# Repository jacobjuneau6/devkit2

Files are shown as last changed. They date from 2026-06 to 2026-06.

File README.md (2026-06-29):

# devkit2

A compact ESP32-S3 development board designed for rapid prototyping and embedded projects.

## Features

- **ESP32-S3-WROOM-1** module — dual-core Xtensa LX7, 2.4 GHz Wi-Fi, BLE 5.0, 8 MB PSRAM, 16 MB Flash
- **USB-C** connector for power, programming, and serial monitor
- **WS2812B** addressable RGB LED on GPIO 2
- **microSD card** slot (TF-PUSH) connected via SPI
- **2× tactile push buttons** — Boot (GPIO 0) and Reset (EN)
- **2× 20-pin breakout headers** bringing out all available GPIO, power rails, and peripheral signals
- **3.3 V LDO regulator** (TPS74533) — up to 500 mA output, 6.5 V max input
- **Compact form factor** — fits on a breadboard with one row of pins free on each side

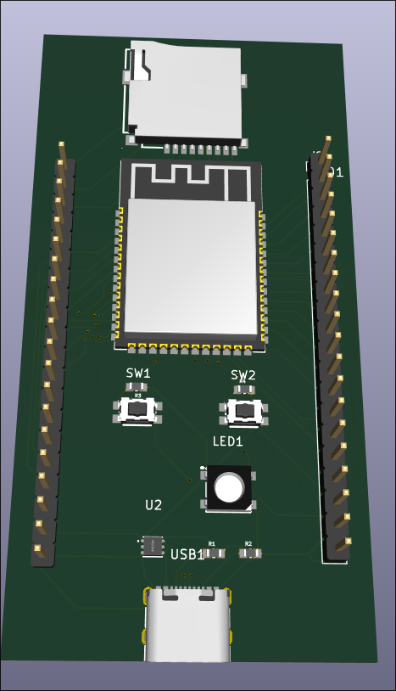
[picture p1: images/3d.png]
devkit2 3D render


## Pin Map

```
                    ┌──────────────────┐
             3.3V —│ J1               │— GND
             EN   —│                  │— VIN (5 V)
            IO4   —│                  │— IO5
            IO6   —│                  │— IO7
            IO15  —│                  │— IO8
            IO16  —│                  │— IO9
            IO17  —│                  │— IO10
            IO18  —│                  │— IO11
            IO19  —│                  │— IO12
            IO20  —│                  │— IO13
            IO21  —│    ESP32-S3      │— IO14
            IO26  —│    devkit2       │— IO38
            IO35  —│                  │— IO39
            IO36  —│                  │— IO40
            IO37  —│                  │— IO41
            IO42  —│                  │— IO45
            IO43  —│                  │— IO46
            IO44  —│                  │— IO47
            GND   —│                  │— IO2  (onboard LED)
            5 V   —│                  │— IO0  (Boot button)
                   └──────────────────┘
```

| Peripheral | GPIO | Notes |
|---|---|---|
| WS2812B LED | 2 | DIN, use NeoPixel lib |
| Boot button | 0 | Pull LOW to enter download mode |
| Reset button| EN | Pulls EN pin LOW |
| microSD CS  | 5 | SPI chip select |
| microSD MOSI| 11 | SPI data |
| microSD MISO| 13 | SPI data |
| microSD SCK | 12 | SPI clock |

## Getting Started

### 1. Add Board Support

Install the **esp32** board package by Espressif in the Arduino IDE:

1. Open **File → Preferences**
2. Add this URL to **Additional Boards Manager URLs**:
   ```
   https://espressif.github.io/arduino-esp32/package_esp32_index.json
   ```
3. Open **Tools → Board → Boards Manager**, search for `esp32`, and install **esp32 by Espressif Systems**

### 2. Select Board Settings

| Setting | Value |
|---|---|
| Board | ESP32S3 Dev Module |
| USB CDC On Boot  | Enabled |
| Flash Size | 16 MB (128 Mb) |
| PSRAM | OPI PSRAM |
| Upload Mode | UART / Hardware CDC |

### 3. Install Libraries

Install these libraries via **Tools → Manage Libraries**:

- **Adafruit NeoPixel** — for the onboard WS2812B LED
- **SD** (built-in, or **SdFat**) — for the microSD slot

### 4. Upload the Demo

Hold **Boot** (SW1), press and release **Reset** (SW2), then release **Boot** to enter download mode. Open `CODE/demo/demo.ino` in the Arduino IDE, select the correct port, and hit **Upload**.

## Bill of Materials

| Designator | Qty | Value | Footprint | LCSC # |
|---|-----|---|---|---|
| U1 | 1 | ESP32-S3-WROOM-1 | WIRELM-SMD ESP32-S3-WROOM-1 | C2913201  |
| U2 | 1 | TPS74533PCQWDRVRQ1  | WSON-6 2.0×2.0 mm | C2860924  |
| USB1 | 1 | TYPE-C 16PIN 2MD | USB-C SMD 16-pin | C2765186  |
| LED1 | 1 | WS2812B-B/W | LED-SMD 5.0×5.0 mm | C2761795  |
| CARD1 | 1 | TF PUSH | TF-SMD push-push | C393941 |
| J1, J2 | 2 | PINHD 1×20 Male | PinHeader 1×20 2.54 mm | — |
| SW1, SW2  | 2 | KMR221NGLFS | KEY-SMD 4.2×2.8 mm | C269272 |
| R1, R2 | 2 | RT0603BRE075K1L | 0603 (1608 Metric) | C728607 |
| R3, R4 | 2 | RT0603BRE0710KL | 0603 (1608 Metric) | C6277183  |

- **R1, R2** = 5.1 kΩ thin-film — USB-C CC pull-downs
- **R3, R4** = 10 kΩ thick-film — EN and BOOT pull-ups
- **SW1** = Reset, **SW2** = Boot
- All passives are 0603 imperial (1608 metric)

## Hardware

Board files live in [`BOARD/`](BOARD/). The project was designed in **KiCad 8**.

**🔗 [View schematic & PCB interactively on KiCanvas](https://kicanvas.org/?github=https://github.com/jacobjuneau6/devkit2/blob/main/BOARD/Board/Board.kicad_pro)**

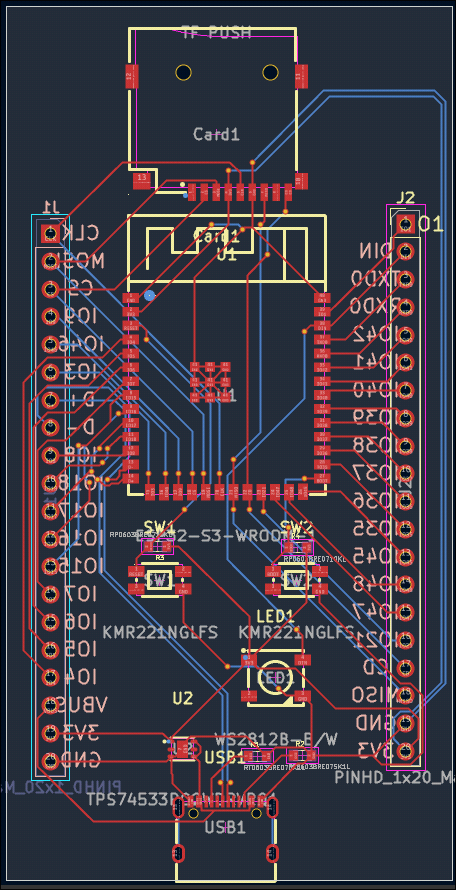
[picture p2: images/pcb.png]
PCB layout


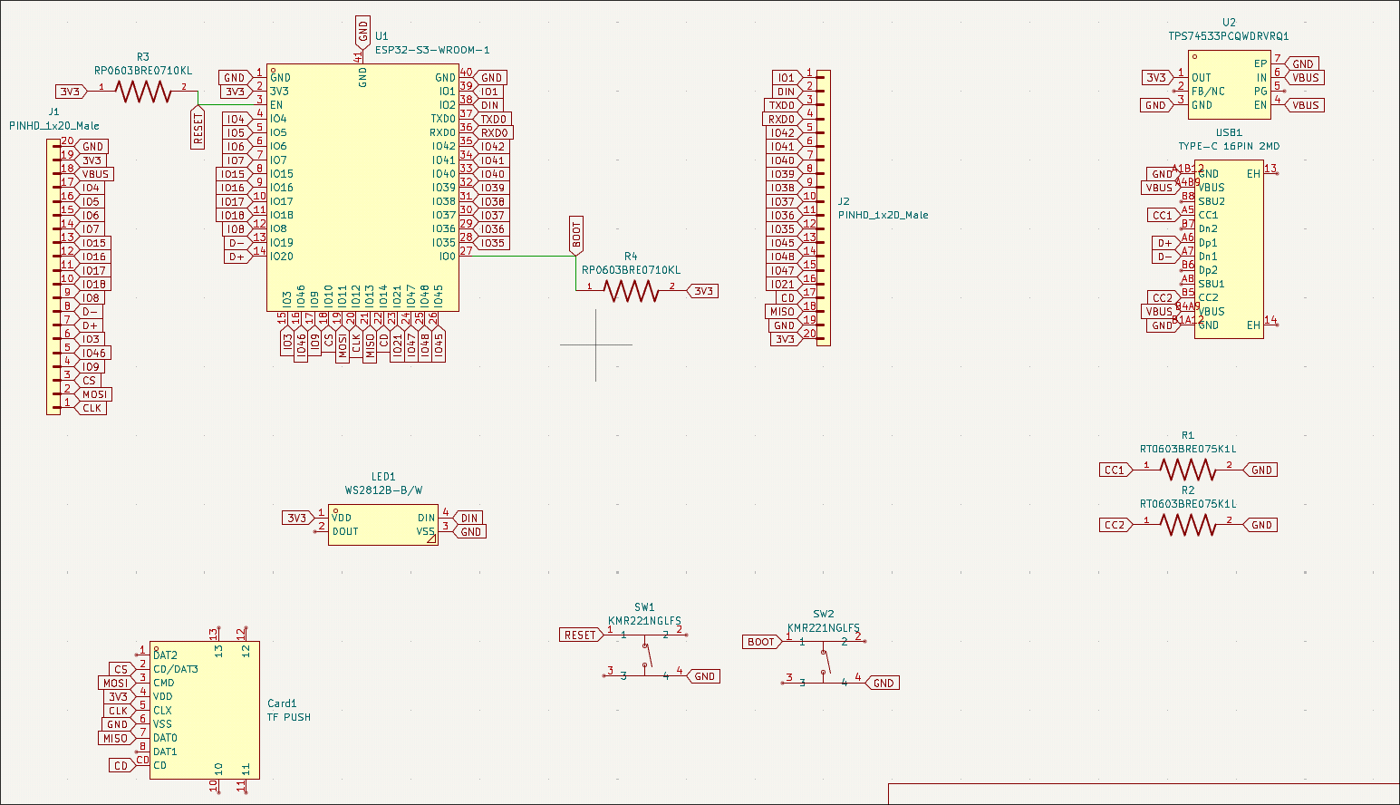
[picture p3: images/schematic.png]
Schematic


| Directory | Contents |
|---|---|
| `BOARD/Board/` | Schematic, PCB, project files |
| `BOARD/Board/gbrs/` | Gerber files (JLCPCB ready)  |
| `BOARD/Board/production/` | BOM, CPL, netlist |
| `BOARD/CAD/` | 3D STEP model |

## License

Hardware and software are released under the [MIT License](LICENSE).

---

Built by [jacobjuneau6](https://github.com/jacobjuneau6)

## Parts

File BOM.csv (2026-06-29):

Designator | Footprint | Quantity | Value | LCSC Part #
CARD1 | TF-SMD_TF-PUSH | 1 | TF PUSH | C393941
J1, J2 | PinHeader_1x20_P2.54mm_Vertical | 2 | PINHD_1x20_Male
LED1 | LED-SMD_4P-L5.0-W5.0-TL_WS2812B-B | 1 | WS2812B-B/W | C2761795
R1, R2 | RESC1608X55N | 2 | RT0603BRE075K1L | C728607
R3, R4 | RESC1608X55N | 2 | RP0603BRE0710KL | C6277183
SW1, SW2 | KEY-SMD_4P-L4.2-W2.8-P1.60-LS4.6 | 2 | KMR221NGLFS | C269272
U1 | WIRELM-SMD_ESP32-S3-WROOM-1 | 1 | ESP32-S3-WROOM-1 | C2913201
U2 | WSON-6_L2.0-W2.0-P0.65-TL-EP | 1 | TPS74533PCQWDRVRQ1 | C2860924
USB1 | USB-C-SMD_TYPE-C-16PIN-2MD-073 | 1 | TYPE-C 16PIN 2MD | C2765186

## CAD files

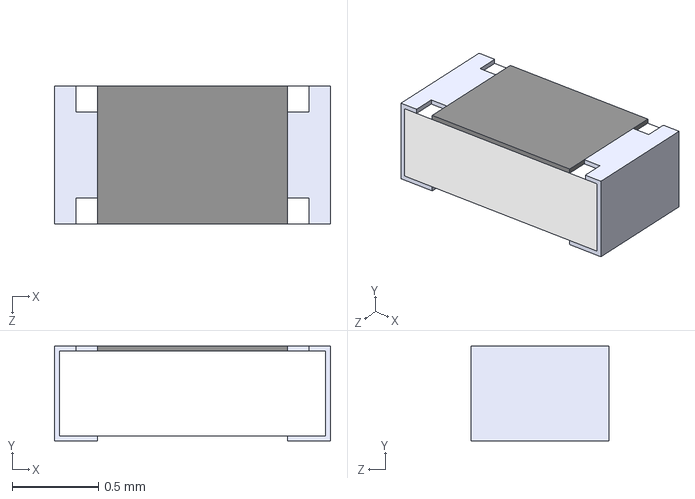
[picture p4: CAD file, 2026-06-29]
BOARD/Board/staging/RT0603BRE075K1L/RT0603BRE075K1L.step
1.60 x 0.55 x 0.8 mm

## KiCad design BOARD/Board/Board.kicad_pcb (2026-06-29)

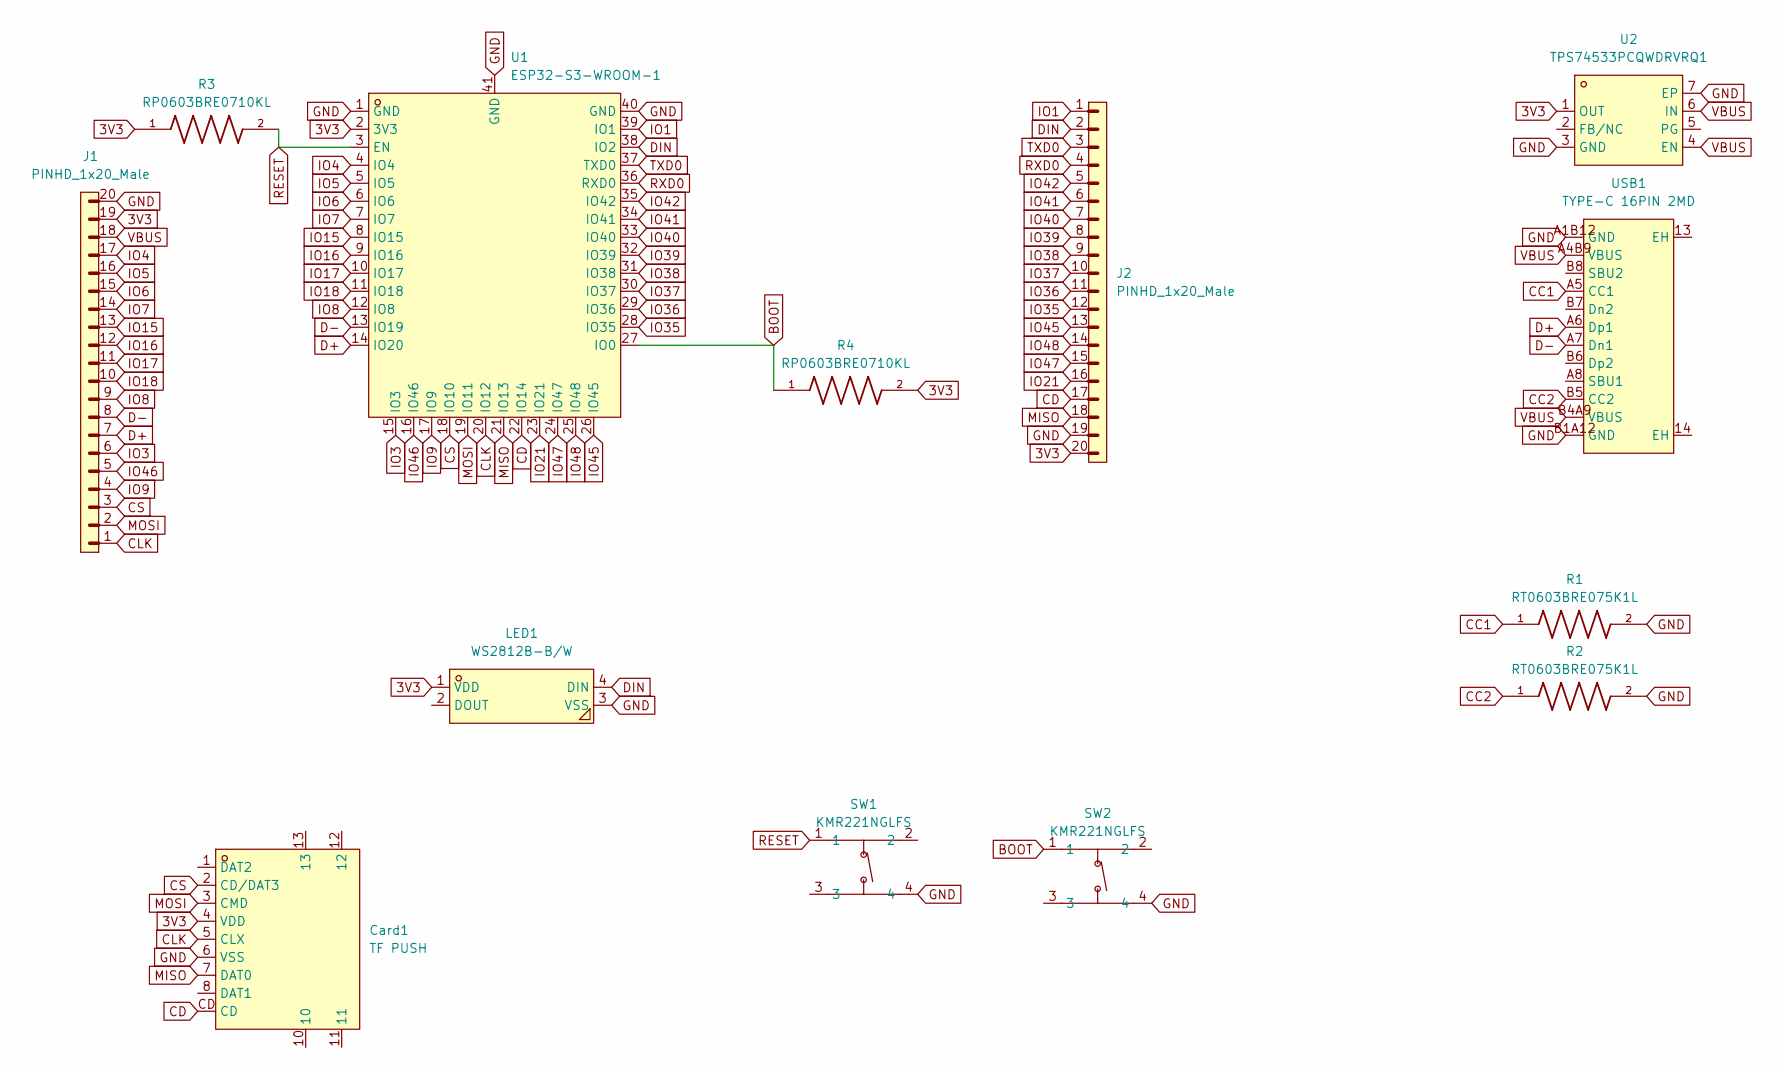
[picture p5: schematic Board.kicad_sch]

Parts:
Card1: TF PUSH; TF-SMD_TF-PUSH; MPN TF PUSH; LCSC Part C393941
J1, J2: PINHD_1x20_Male; PinHeader_1x20_P2.54mm_Vertical
LED1: WS2812B-B/W; LED-SMD_4P-L5.0-W5.0-TL_WS2812B-B; MPN WS2812B-B/T; LCSC Part C2761795
R1, R2: RT0603BRE075K1L; RESC1608X55N; MPN TYPE-C 16PIN 2MD(073); LCSC Part C728607
R3, R4: RP0603BRE0710KL; RESC1608X55N; MPN TYPE-C 16PIN 2MD(073); LCSC Part C6277183
SW1, SW2: KMR221NGLFS; KEY-SMD_4P-L4.2-W2.8-P1.60-LS4.6; MPN KMR221NGLFS; LCSC Part C269272
U1: ESP32-S3-WROOM-1; WIRELM-SMD_ESP32-S3-WROOM-1; MPN ESP32-S3-WROOM-1-N8R8; LCSC Part C2913201
U2: TPS74533PCQWDRVRQ1; WSON-6_L2.0-W2.0-P0.65-TL-EP; MPN TPS74533PCQWDRVRQ1; LCSC Part C2860924
USB1: TYPE-C 16PIN 2MD; USB-C-SMD_TYPE-C-16PIN-2MD-073; MPN TYPE-C 16PIN 2MD(073); LCSC Part C2765186

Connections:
3V3: Card1.4 (VDD), J1.19, J2.20, LED1.1 (VDD), R3.1, R4.2, U1.2 (3V3), U2.1 (OUT)
BOOT: R4.1, SW2.1, U1.27 (IO0)
CC1: R1.1, USB1.A5 (CC1)
CC2: R2.1, USB1.B5 (CC2)
CD: Card1.CD, J2.17, U1.22 (IO14)
CLK: Card1.5 (CLX), J1.1, U1.20 (IO12)
CS: Card1.2 (CD/DAT3), J1.3, U1.18 (IO10)
D+: J1.7, U1.14 (IO20), USB1.A6 (Dp1)
D-: J1.8, U1.13 (IO19), USB1.A7 (Dn1)
DIN: J2.2, LED1.4 (DIN), U1.38 (IO2)
GND: Card1.6 (VSS), J1.20, J2.19, LED1.3 (VSS), R1.2, R2.2, SW1.4, SW2.4, U1.1 (GND), U1.40 (GND), U1.41 (GND), U2.3 (GND), U2.7 (EP), USB1.A1B12 (GND), USB1.B1A12 (GND)
IO1: J2.1, U1.39 (IO1)
IO3: J1.6, U1.15 (IO3)
IO4: J1.17, U1.4 (IO4)
IO5: J1.16, U1.5 (IO5)
IO6: J1.15, U1.6 (IO6)
IO7: J1.14, U1.7 (IO7)
IO8: J1.9, U1.12 (IO8)
IO9: J1.4, U1.17 (IO9)
IO15: J1.13, U1.8 (IO15)
IO16: J1.12, U1.9 (IO16)
IO17: J1.11, U1.10 (IO17)
IO18: J1.10, U1.11 (IO18)
IO21: J2.16, U1.23 (IO21)
IO35: J2.12, U1.28 (IO35)
IO36: J2.11, U1.29 (IO36)
IO37: J2.10, U1.30 (IO37)
IO38: J2.9, U1.31 (IO38)
IO39: J2.8, U1.32 (IO39)
IO40: J2.7, U1.33 (IO40)
IO41: J2.6, U1.34 (IO41)
IO42: J2.5, U1.35 (IO42)
IO45: J2.13, U1.26 (IO45)
IO46: J1.5, U1.16 (IO46)
IO47: J2.15, U1.24 (IO47)
IO48: J2.14, U1.25 (IO48)
MISO: Card1.7 (DAT0), J2.18, U1.21 (IO13)
MOSI: Card1.3 (CMD), J1.2, U1.19 (IO11)
RESET: R3.2, SW1.1, U1.3 (EN)
RXD0: J2.4, U1.36 (RXD0)
TXD0: J2.3, U1.37 (TXD0)
VBUS: J1.18, U2.4 (EN), U2.6 (IN), USB1.A4B9 (VBUS), USB1.B4A9 (VBUS)

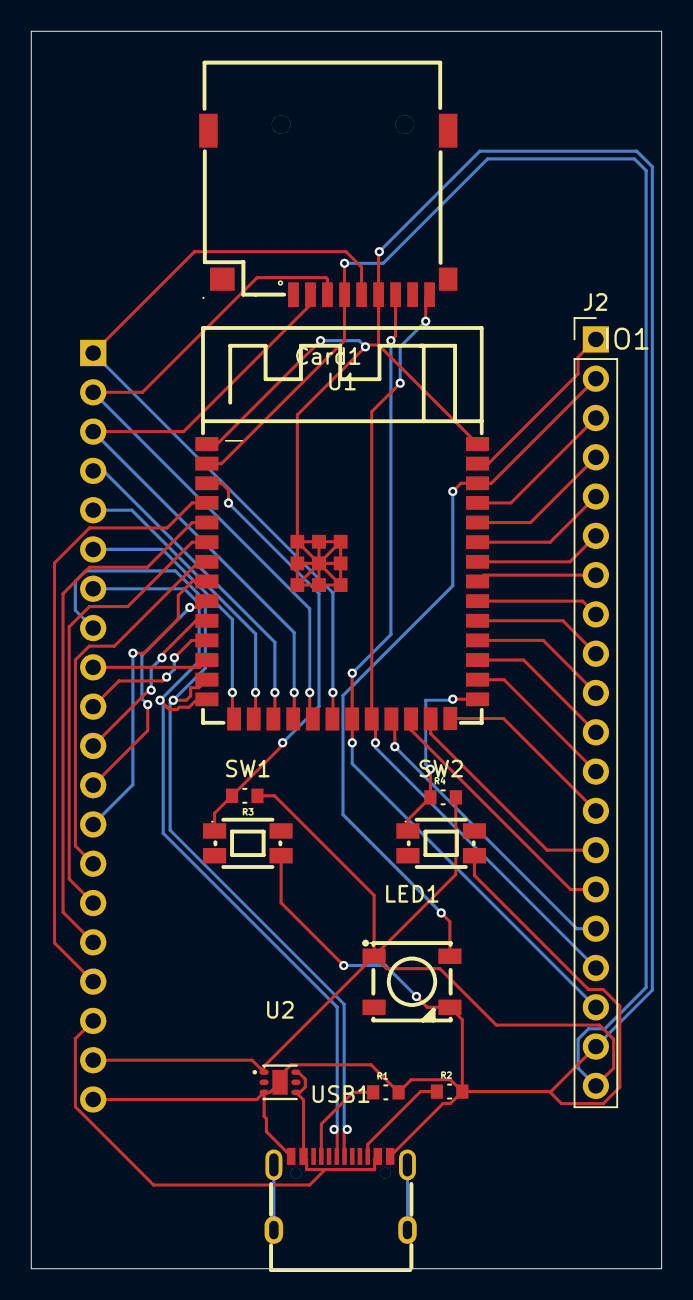
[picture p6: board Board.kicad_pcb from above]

Board: 2 copper layers, 40.8 x 80.0 mm, 13 parts (1 on the bottom side), 42 nets.

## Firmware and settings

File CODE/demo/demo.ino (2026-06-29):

/**
 * devkit2 Demo Sketch
 *
 * Demonstrates the onboard peripherals of the devkit2 ESP32-S3 board:
 *   - WS2812B RGB LED (GPIO 48) — color cycle + blink patterns
 *   - Boot button (GPIO 0) — cycles through modes
 *   - USB-CDC serial output
 *
 * Hardware:
 *   Board: ESP32S3 Dev Module
 *   USB CDC On Boot: Enabled
 *   PSRAM: OPI PSRAM
 *
 * Dependencies:
 *   - Adafruit NeoPixel library
 */

#include <Adafruit_NeoPixel.h>

// ── Pin Definitions ────────────────────────────────────────────────

#define PIN_NEOPIXEL    2    // Onboard WS2812B data line
#define PIN_BOOT_BTN    0    // Boot button (active low)

// ── Constants ──────────────────────────────────────────────────────

#define NUMPIXELS       1    // Single onboard NeoPixel
#define DEBOUNCE_MS    50    // Button debounce window
#define SERIAL_BAUD 115200

// ── Globals ────────────────────────────────────────────────────────

Adafruit_NeoPixel pixels(NUMPIXELS, PIN_NEOPIXEL, NEO_GRB + NEO_KHZ800);

enum Mode {
  MODE_RAINBOW,       // Smooth hue sweep across the wheel
  MODE_BREATHE,       // Single-color breathing pulse
  MODE_STROBE,        // Fast RGB flash
  MODE_BLINK,         // Simple on/off blink in white
  MODE_COUNT
};

Mode    currentMode   = MODE_RAINBOW;
uint8_t breatheHue    = 0;
bool    lastBtnState  = HIGH;
unsigned long lastDebounce = 0;
unsigned long lastFrame    = 0;

// ── Setup ──────────────────────────────────────────────────────────

void setup() {
  // ── Serial ──
  Serial.begin(SERIAL_BAUD);
  delay(500);  // Let CDC settle
  Serial.println();
  Serial.println(F("╔══════════════════════════════╗"));
  Serial.println(F("║        devkit2  demo        ║"));
  Serial.println(F("╚══════════════════════════════╝"));
  Serial.println();
  Serial.println(F("Press BOOT button to cycle modes."));
  Serial.println();

  // ── NeoPixel ──
  pixels.begin();
  pixels.setBrightness(32);  // Keep it comfortable (0–255)
  pixels.clear();
  pixels.show();

  // ── Boot Button ──
  pinMode(PIN_BOOT_BTN, INPUT_PULLUP);  // External pull-up + internal

  Serial.printf("Mode: %s\n", modeName(currentMode));
}

// ── Loop ───────────────────────────────────────────────────────────

void loop() {
  unsigned long now = millis();

  // ── Button handling (debounced, falling edge) ──
  bool reading = digitalRead(PIN_BOOT_BTN);
  if (reading != lastBtnState) {
    lastDebounce = now;
  }
  if ((now - lastDebounce) > DEBOUNCE_MS) {
    if (reading == LOW && lastBtnState == HIGH) {
      // Button pressed — advance mode
      currentMode = (Mode)((currentMode + 1) % MODE_COUNT);
      Serial.printf("Mode: %s\n", modeName(currentMode));
      pixels.clear();
      pixels.show();
    }
  }
  lastBtnState = reading;

  // ── Animation (non-blocking) ──
  static uint16_t frame = 0;
  frame++;

  switch (currentMode) {
    case MODE_RAINBOW:   animateRainbow(frame);   break;
    case MODE_BREATHE:   animateBreathe(frame);   break;
    case MODE_STROBE:    animateStrobe(frame);    break;
    case MODE_BLINK:     animateBlink(frame);     break;
  }

  delay(5);  // ~200 fps max — plenty for human vision
}

// ═══════════════════════════════════════════════════════════════════
//  Animation helpers
// ═══════════════════════════════════════════════════════════════════

// ── Rainbow: continuous hue sweep ──────────────────────────────────

void animateRainbow(uint16_t frame) {
  uint32_t color = pixels.ColorHSV(frame * 256);  // 256 steps per hue tick
  pixels.setPixelColor(0, color);
  pixels.show();
}

// ── Breathe: single-color brightness pulse ─────────────────────────

void animateBreathe(uint16_t frame) {
  // Slowly rotate the hue
  if (frame % 10 == 0) breatheHue++;

  // Triangle wave for breathing effect
  uint16_t phase = frame & 0x1FF;  // 0–511
  uint8_t brightness;
  if (phase < 256) {
    brightness = phase;        // Fade in
  } else {
    brightness = 511 - phase;  // Fade out
  }

  uint32_t color = pixels.ColorHSV(breatheHue * 256);
  pixels.setPixelColor(0, color);
  pixels.setBrightness(constrain(brightness, 1, 255));
  pixels.show();
}

// ── Strobe: fast color flashes ─────────────────────────────────────

void animateStrobe(uint16_t frame) {
  static const uint32_t colors[] = {
    0xFF0000,  // Red
    0x00FF00,  // Green
    0x0000FF,  // Blue
    0xFFFFFF,  // White
  };
  static const int numColors = sizeof(colors) / sizeof(colors[0]);

  uint8_t phase = (frame / 20) % (numColors * 2);
  if (phase < numColors) {
    pixels.setBrightness(128);
    pixels.setPixelColor(0, colors[phase]);
  } else {
    pixels.setBrightness(0);  // Off between flashes
  }
  pixels.show();
  pixels.setBrightness(32);  // Restore for other modes
}

// ── Blink: simple on/off in warm white ─────────────────────────────

void animateBlink(uint16_t frame) {
  bool on = ((frame / 100) % 2) == 0;  // 2 Hz
  if (on) {
    pixels.setBrightness(64);
    pixels.setPixelColor(0, pixels.Color(255, 200, 100));  // Warm white
  } else {
    pixels.setBrightness(0);
  }
  pixels.show();
  pixels.setBrightness(32);
}

// ── Mode name helper ───────────────────────────────────────────────

const char* modeName(Mode m) {
  switch (m) {
    case MODE_RAINBOW:  return "Rainbow";
    case MODE_BREATHE:  return "Breathe";
    case MODE_STROBE:   return "Strobe";
    case MODE_BLINK:    return "Blink";
    default:            return "???";
  }
}

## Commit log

2026-06-29 add pcb, readme & code
    [Board-B_Cu.gbr, Board-B_Mask.gbr, Board-B_Paste.gbr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]
2026-06-29 add BOM.csv to main repo
    [BOM.csv]
